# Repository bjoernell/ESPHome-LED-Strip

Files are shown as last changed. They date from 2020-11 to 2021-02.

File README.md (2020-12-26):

# ESPHome-LED-Strip
This is the repository for my Home Assistant RGB LED-Strip Controller based on ESPHome. 

## Parts list:
I used the following parts to build it:
- Node MCU (ESP8266)
  - control unit with wifi for home assistant
- BD437 Transistor
- Resistors that have a value of approximately 1800Ω
- 8 port dip switch
  - for interrupting the connection between led's and MCU, otherwise the MCU won't boot after disconnecting it from the power supply. I didn't find three pins that are not used       for starting ESPHome or the MCU itself....
- 9V 2A Power Supply
  - the maximum voltage you can use depends on your board, I can power mine with up to 10V so 9V works just fine
- Standard switch
  - to turn the whole circuit on and off in case something is not working (didn't happen so far)
- 6.35mm jack socket and plug 

## Circuit:
The following picture shows a schematic of how i've wired everything up:
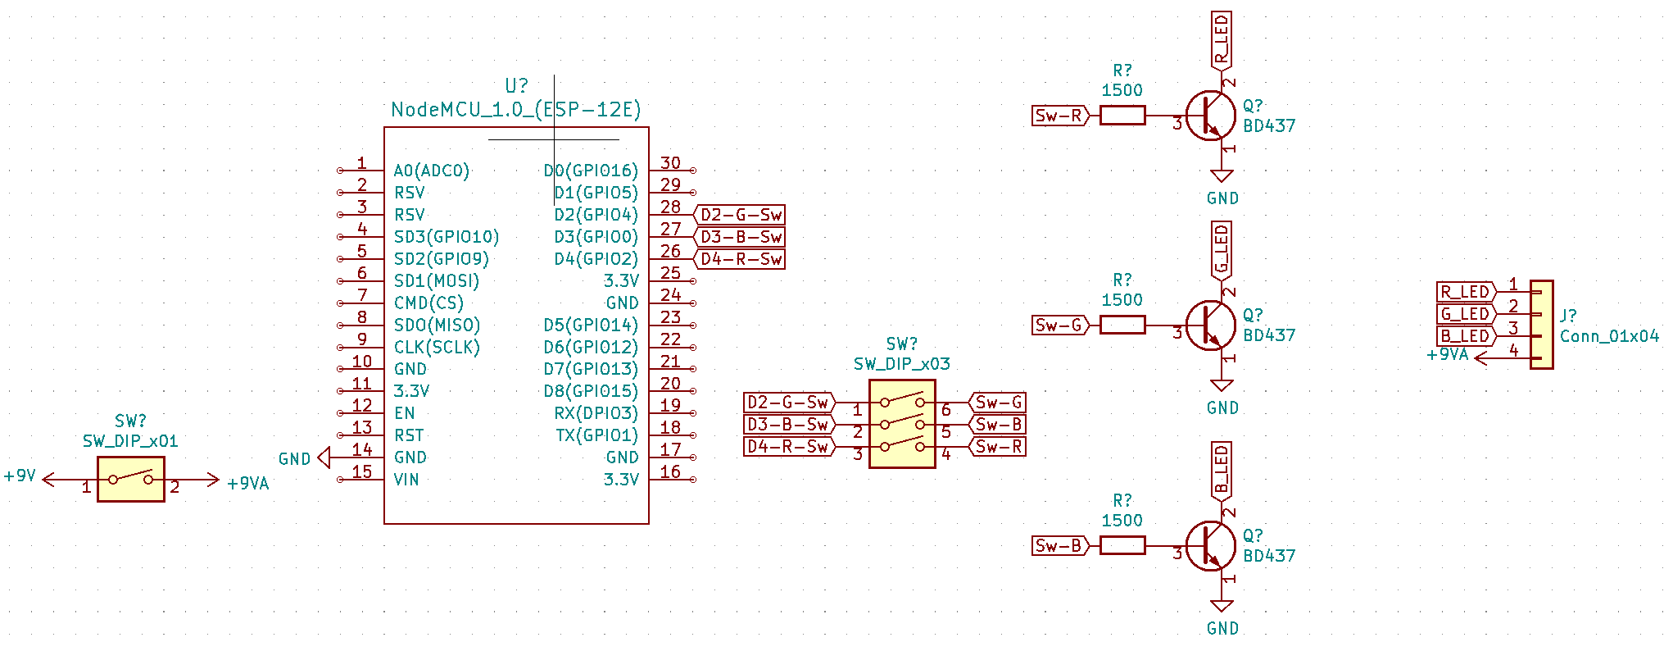
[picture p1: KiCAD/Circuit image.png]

I used three transistors one for each color to regulate every pwm value by itself. For the base resistor I calculated a value of 1850Ω. I think it isn't important. I also use a casual switch and an dip switch. The casual switch is just to turn everything on and off if a restart is required. If I want to restart my MCU I have to disconnect the transistors from the MCU and therefore I use a dip switch. My power supply produces about 9V wich is ok for me. It also makes the circuit more simple because I dont have to use a voltage regulator and connect it directly to the MCU's Vin pin. To get the power in my case I used 6.35mm jack socket and plug because I had this laying around.
At the moment the only working KiCad directory at the moment is "Circuit Board" but I will finish the others as soon as my ordered ESP12F modules arive to make the project much smaller.

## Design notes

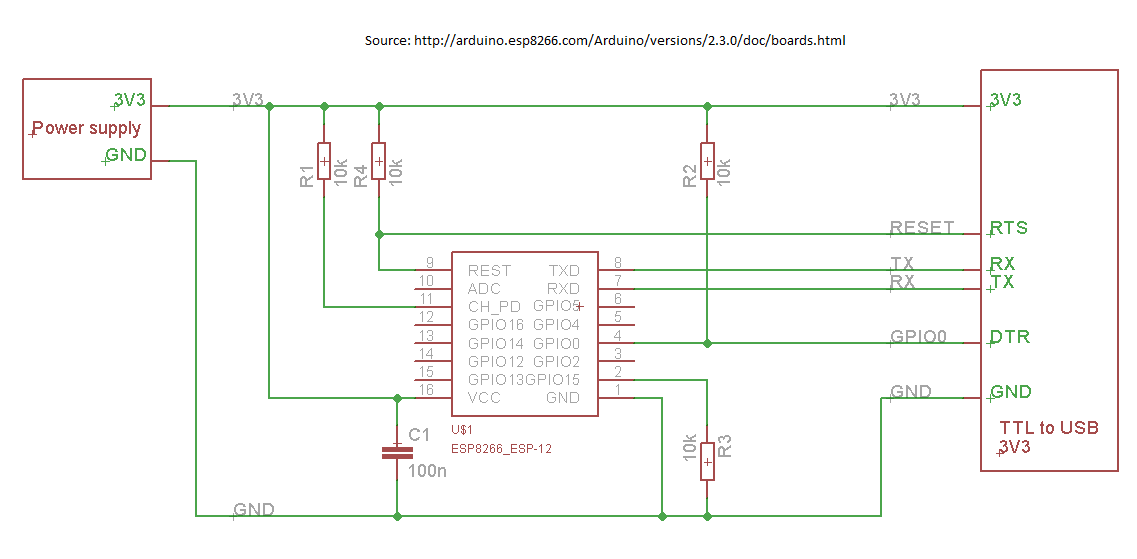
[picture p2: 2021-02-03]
KiCAD/ESP Flashing image.png

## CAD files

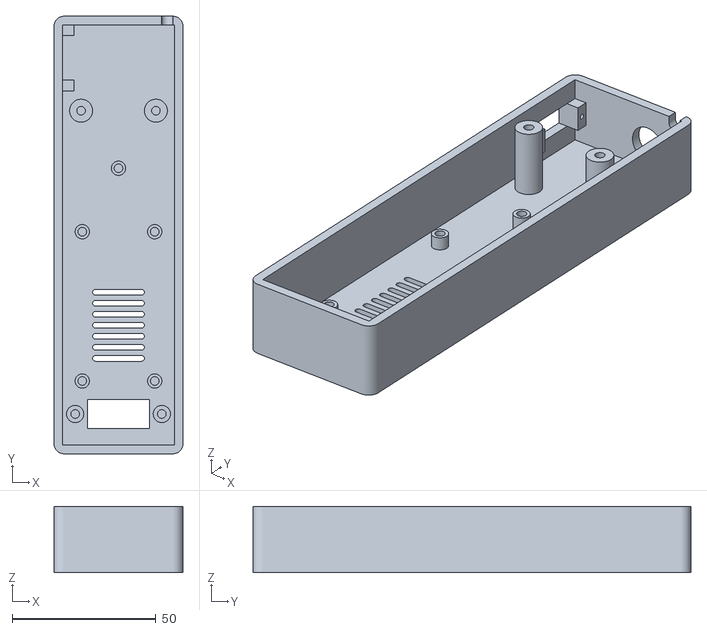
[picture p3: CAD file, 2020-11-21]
Case STL files/Case top.stl
44.8 x 152.1 x 23.0

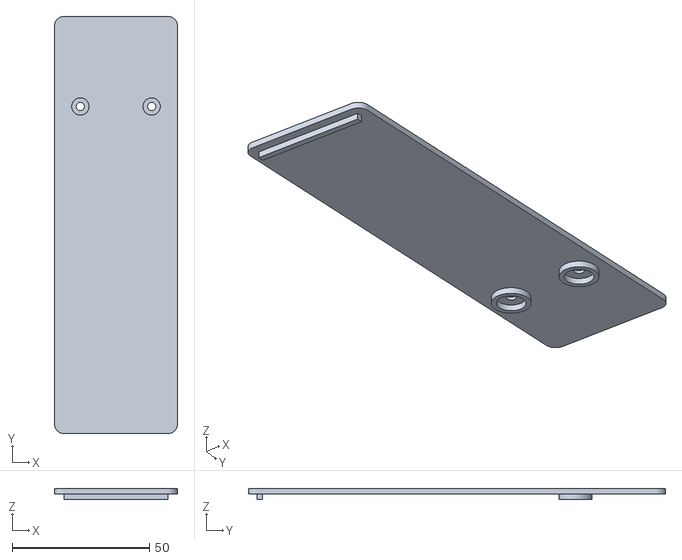
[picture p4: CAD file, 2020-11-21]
Case STL files/Case bottom.stl
44.8 x 152.1 x 4.00

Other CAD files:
Case Fusion360 files/ESPHome LEDControl Case.f3d

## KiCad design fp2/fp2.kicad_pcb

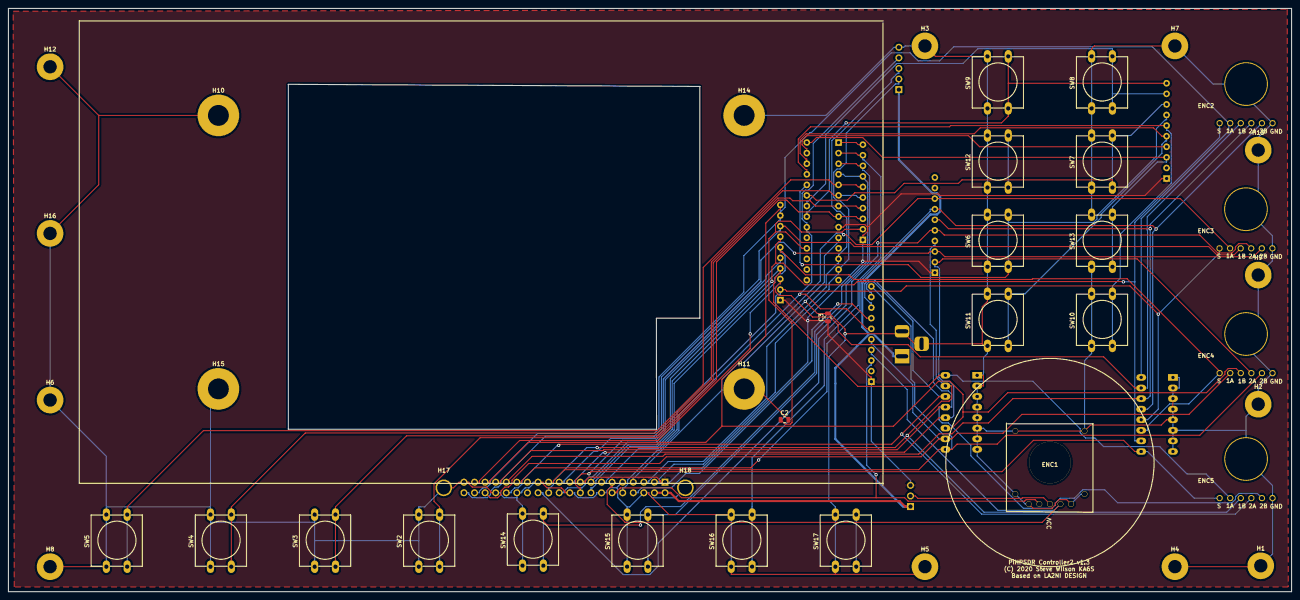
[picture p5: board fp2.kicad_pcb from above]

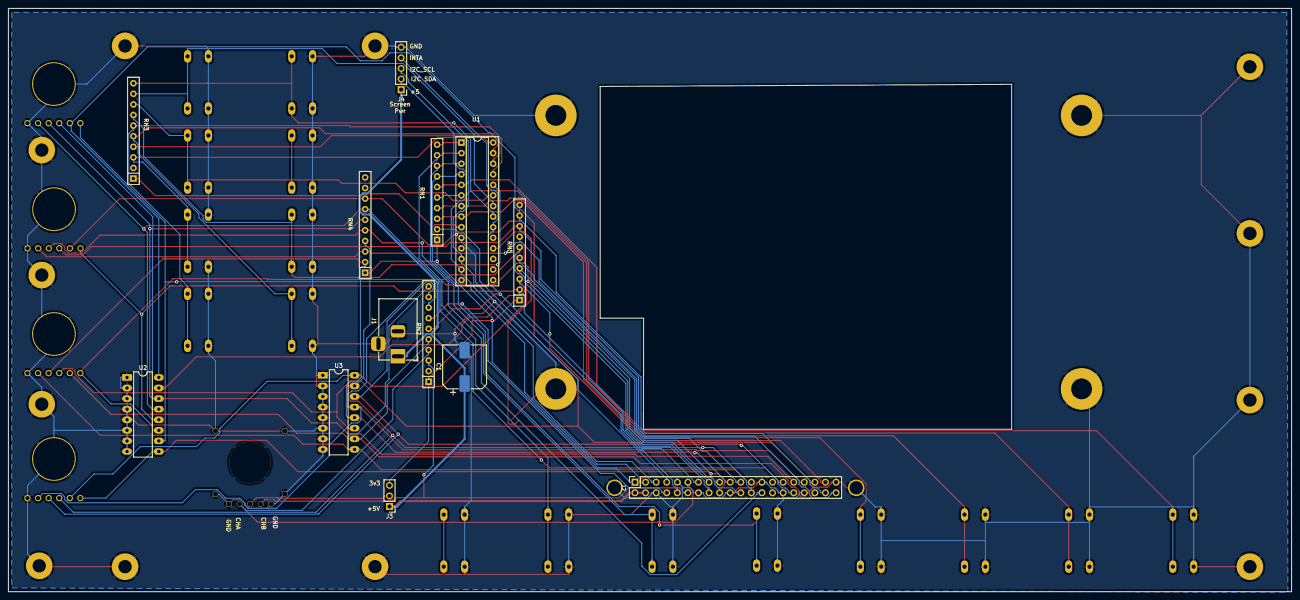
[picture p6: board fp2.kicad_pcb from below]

Board: 2 copper layers, 308.0 x 140.0 mm, 54 parts (13 on the bottom side), 47 nets.

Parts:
C1: 220uF; CP_Elec_10x10
C2: 0.01uF; C_0805_2012Metric
C3: 10uF; C_0805_2012Metric
ENC1: Rotary_Encoder_HRPG
ENC2, ENC3, ENC4, ENC5: rotary_encoder_elma37a; ELMA_E37A
H1, H2, H3, H4, H5, H6, H7, H8, H9, H12, H13, H16, H17, H18: MountingHole_Pad; MountingHole_3.2mm_M3_Pad
H10, H11, H14, H15: MountingHole_Pad; MountingHole_5mm_Pad
J1: Barrel_Jack_MountingPin; BarrelJack_Horizontal
J2: Conn_02x20_Odd_Even; PinSocket_2x20_P2.54mm_Vertical
J3: Conn_01x03; PinHeader_1x03_P2.54mm_Vertical
J4: Conn_01x05; PinHeader_1x05_P2.54mm_Vertical
RN1, RN2, RN3, RN4, RN5: 10K; R_Array_SIP10
SW2, SW3, SW4, SW5, SW6, SW7, SW8, SW9, SW10, SW11, SW12, SW13, SW14, SW15, SW16, SW17: SW_SPST; SW_PUSH-12mm
U1: MCP23017_SO; DIP-28_W7.62mm_Socket
U2, U3: 0.01uF ARRAY; CAP_ARRAY_16

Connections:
/encoder/3V3: C3.1, J2.1, J2.17, J3.3, RN1.1, RN2.1, RN3.1, RN4.1, RN5.1, U1.9
/encoder/5V: C1.1, J1.1, J2.2, J2.4, J3.1, J4.1
/encoder/GBP0: RN1.10, U1.1
/encoder/GPA0: RN3.10, SW9.2, U1.21
/encoder/GPA1: RN3.9, SW8.2, U1.22
/encoder/GPA2: RN3.8, SW7.2, U1.23
/encoder/GPA3: RN3.7, SW6.2, U1.24
/encoder/GPA4: RN3.6, SW10.2, U1.25
/encoder/GPA5: RN3.5, SW11.2, U1.26
/encoder/GPA6': RN3.4, U1.27
/encoder/GPA7: RN3.3, SW13.2, U1.28
/encoder/GPB1: RN1.9, SW16.2, U1.2
/encoder/GPB2: RN1.8, SW15.2, U1.3
/encoder/GPB3: RN1.7, SW14.2, U1.4
/encoder/GPB4: RN1.6, SW5.2, U1.5
/encoder/GPB5: RN1.5, SW4.2, U1.6
/encoder/GPB6: RN1.4, SW3.2, U1.7
/encoder/GPB7: RN1.3, SW2.2, U1.8
/encoder/GPIO4: ENC3.2, J2.7, RN4.8
/encoder/GPIO5: ENC2.5, J2.29, RN4.7, U2.13
/encoder/GPIO6: ENC2.4, J2.31, RN4.6, U2.14
/encoder/GPIO7: ENC3.4, J2.26, RN4.5
/encoder/GPIO8: ENC5.3, J2.24, RN4.4, U3.15
/encoder/GPIO9: ENC3.5, J2.21, RN4.3
/encoder/GPIO10: ENC4.4, J2.19, RN4.2, U3.12
/encoder/GPIO11: ENC4.5, J2.23, RN2.10, U3.9
/encoder/GPIO12: ENC5.4, J2.32, RN2.9, U3.14
/encoder/GPIO13: ENC5.5, J2.33, RN2.8, U3.13
/encoder/GPIO14: J2.8, RN2.7
/encoder/GPIO15: J2.10, J4.4, RN2.6, U1.20
/encoder/GPIO16: ENC4.2, J2.36, RN2.5, U3.10
/encoder/GPIO17: ENC1.2, J2.11, RN2.4
/encoder/GPIO18: ENC1.4, J2.12, RN2.3
/encoder/GPIO19: ENC4.3, J2.35, RN5.10, U3.11
/encoder/GPIO20: ENC2.2, J2.38, RN5.9, U2.16
/encoder/GPIO21: ENC3.3, J2.40, RN5.8
/encoder/GPIO22: ENC2.1, J2.15, RN5.7, U2.10
/encoder/GPIO23: ENC4.1, J2.16, RN5.6, U2.11
/encoder/GPIO24: ENC5.1, J2.18, RN5.5, U2.9
/encoder/GPIO25: ENC5.2, J2.22, RN5.4, U3.16
/encoder/GPIO26: ENC2.3, J2.37, RN5.3, U2.15
/encoder/GPIO27: ENC3.1, J2.13, RN5.2, U2.12
/encoder/I2C_SCL: J2.5, J4.3, U1.12
/encoder/I2C_SDA: J2.3, J4.2, U1.13
GND: C1.2, C2.2, C3.2, ENC1.1, ENC1.5, ENC2.6, ENC3.6, ENC4.6, ENC5.6, H1.1, H2.1, H3.1, H4.1, H5.1, H6.1, H7.1, H8.1, H9.1, H10.1, H11.1, H12.1, H13.1, H14.1, H15.1, H16.1, H17.1, H18.1, J1.2, J1.MP, J2.6, J2.9, J2.14, J2.20, J2.25, J2.30, J2.34, J2.39, J4.5, SW2.1, SW3.1, SW4.1, SW5.1, SW6.1, SW7.1, SW8.1, SW9.1, SW10.1, SW11.1, SW12.1, SW13.1, SW14.1, SW15.1, SW16.1, SW17.1, U1.10, U2.1, U2.2, U2.3, U2.4, U2.5, U2.6, U2.7, U2.8, U3.1, U3.2, U3.3, U3.4, U3.5, U3.6, U3.7, U3.8
unnamed: C2.1, RN1.2, U1.18
unnamed: ENC1.3, J3.2

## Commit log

2020-11-19 Designed circuit. Should work
    [Circuit Board.kicad_pcb, Circuit Board.sch]
2020-11-21 added fusion stl and esphome paths
2020-11-21 added stl files and fusion file
    [Case bottom.stl, Case top.stl, ESPHome LEDControl Case.f3d]
2020-12-06 hothing of interest
    [Circuit Board.kicad_pcb, Circuit Board.sch]
2020-12-06 started to design a smaller pcb for ESP12E(hope E will be delivered...)
    [ESP12E Circuit Board.kicad_pcb, ESP12E Circuit Board.sch]
2020-12-07 worked on the smd circuit
    [ESP12E Circuit Board.kicad_pcb, ESP12E Circuit Board.sch]
2020-12-10 added throughole circuit board for esp12
    [ESP12E Circuit Board.kicad_pcb, ESP12E Circuit Board.sch]
2020-12-10 worked on tht circuit
    [ESP12E Circuit Board.kicad_pcb]
2020-12-10 worked on tht
    [ESP12E Circuit Board.kicad_pcb]
2021-02-03 new schematic. old was wrong
    [ESP12 Circuit.kicad_pcb, ESP12 Circuit.sch, ESP12E Circuit Board.kicad_pcb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]
